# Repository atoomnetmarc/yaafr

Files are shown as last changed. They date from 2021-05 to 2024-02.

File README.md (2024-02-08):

# What are this?

This is Yaafr, Yet Another AVR Fusebit Rescuer. It is large because of all the ZIF-sockets and does not even feature any mounting holes. It also has two IDC headers for expanding to programming clips or other adapters to rescue non-dip AVR microcontrollers.

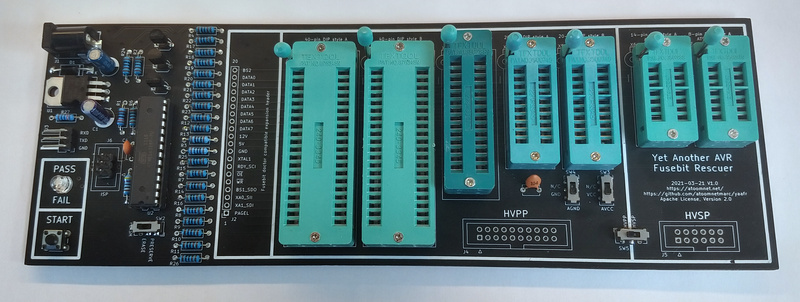
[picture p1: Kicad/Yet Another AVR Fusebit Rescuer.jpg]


It is be able to restore wrongly fused or locked AVR microcontrollers that support high voltage parallel (HVPP) programming or high voltage serial programming (HVSP).

This circuit has been inspired by these projects:

[RescueAVR](https://github.com/felias-fogg/RescueAVR) by Bernhard.\
[AVR Fuse Rescue Shield for Arduino Uno](https://github.com/4x1md/avr_frs_shield) by Dmitry Melnichansky.\
[Arduino-based AVR High Voltage Programmer](https://mightyohm.com/blog/2008/09/arduino-based-avr-high-voltage-programmer/) by Jeff Keyzer.\
[Atmega Fusebit Doctor](https://web.archive.org/web/20180225102717/http://mdiy.pl/atmega-fusebit-doctor-hvpp/?lang=en) by Paweł Kisielewski.

Firmware update 2.11 from the Atmega Fusebit Doctor for the atmega328p has been tested and is working. The [original site](https://files.elektroda.pl/437268,atmega-hvpp-fusebit-doctor_update11.html) does not exist anymore, but [SukkoPera](https://github.com/SukkoPera) has been so kind to archive the remains: https://github.com/SukkoPera/avr-fusebit-doctor/

Firmware from RescueAVR in FBD_MODE works also, but may not contain support for all the chips (such as the AT90S1200).

# Status

This project is working for me, I can rescue all my locked AVRs. See below for what I have tested and validated to be working.

While the schematic was carefully made, the PCB has not been fully tested yet.

I added the possibility to switch on and off AGND and AVCC because in many datasheets in one instance they must be connected and in the next they must not, however leaving the switches always on connected when it does not need to be then the rescues seem to work just fine.

# Checklists

## Functionality

| Thing | Tested and working? |
| -- | -- |
| 40-pin DIP style A | :ballot_box_with_check: |
| 40-pin DIP style B | :ballot_box_with_check: |
| 28-pin DIP style A | :ballot_box_with_check: |
| 20-pin DIP style A | :ballot_box_with_check: |
| 20-pin DIP style B | :ballot_box_with_check: |
| 14-pin DIP style A | :ballot_box_with_check: |
| 8-pin DIP style A | :ballot_box_with_check: |
| AVR Atmega fusebit doctor firmware 2.11 | :ballot_box_with_check: |
| RescueAVR firmware | :ballot_box_with_check: |
| Serial connection | :ballot_box_with_check: |
| Fusebit doctor compatible expansion header | :ballot_box_with_check: |
| HVPP expansion header | :black_square_button: |
| HVSP expansion header | :black_square_button: |

## 40-pin DIP style A (AT90S8535)

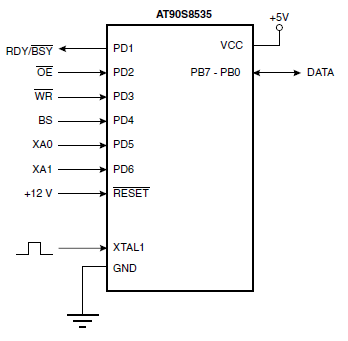
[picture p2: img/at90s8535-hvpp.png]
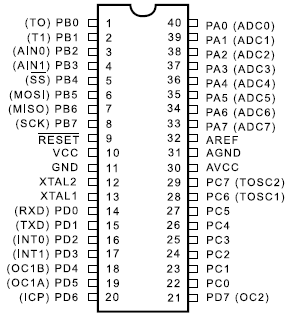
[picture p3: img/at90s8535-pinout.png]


| Model | Signature | Working |
| -- | -- | -- |
| AT90S8535 | 0x1E 0x93 0x03 | :ballot_box_with_check: |
| ATmega8535 | 0x1E 0x93 0x08 | :ballot_box_with_check: |
| ATmega163 | 0x1E 0x94 0x02 | :ballot_box_with_check: |
| ATmega323 | 0x1E 0x95 0x01 | :ballot_box_with_check: |
| ATmega16A | 0x1E 0x94 0x03 | :ballot_box_with_check: |
| ATmega32A | 0x1E 0x95 0x02 | :ballot_box_with_check: |
| ATmega324A | 0x1E 0x95 0x15 | :ballot_box_with_check: |
| ATmega644PA | 0x1E 0x96 0x0A | :ballot_box_with_check: |
| ATmega1284P | 0x1E 0x97 0x05 | :ballot_box_with_check: |

## 40-pin DIP style B (AT90S8515)

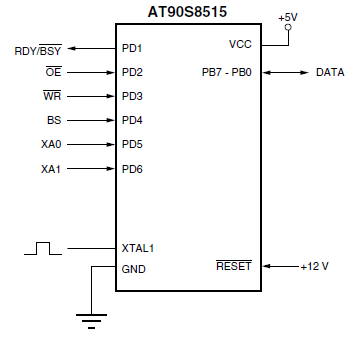
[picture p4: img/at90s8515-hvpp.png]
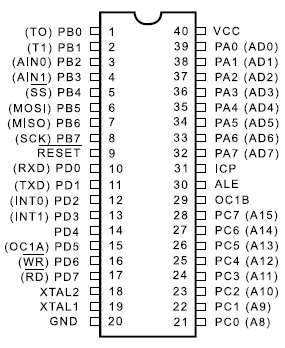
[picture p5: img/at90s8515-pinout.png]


| Model | Signature | Working |
| -- | -- | -- |
| AT90S4414 | 0x1E 0x92 0x01 | :ballot_box_with_check: |
| AT90S8515 | 0x1E 0x93 0x01 | :ballot_box_with_check: |
| ATmega8515 | 0x1E 0x93 0x06 | :ballot_box_with_check: |
| ATmega161 | 0x1E 0x94 0x01 | :ballot_box_with_check: |
| ATmega162 | 0x1E 0x94 0x04 | :ballot_box_with_check: |

## 28-pin DIP style A (AT90S2333)

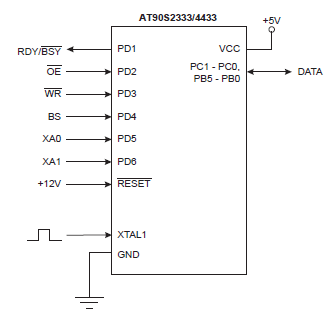
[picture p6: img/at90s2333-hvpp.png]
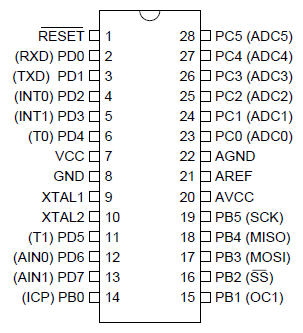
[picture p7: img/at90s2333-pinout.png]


| Model | Signature | Working |
| -- | -- | -- |
| AT90S2333 | 0x1E 0x91 0x05 | :ballot_box_with_check: |
| AT90S4433 | 0x1E 0x92 0x03 | :ballot_box_with_check: |
| ATmega8 | 0x1E 0x93 0x07 | :ballot_box_with_check: |
| ATmega48  | 0x1E 0x92 0x05 | :ballot_box_with_check: |
| ATmega88  | 0x1E 0x93 0x0A | :ballot_box_with_check: |
| ATmega168 | 0x1E 0x94 0x06 | :ballot_box_with_check: |
| ATmega328 | 0x1E 0x95 0x14 | :ballot_box_with_check: |
| ATtiny48  | 0x1E 0x92 0x09 | :ballot_box_with_check: |
| ATtiny88  | 0x1E 0x93 0x11 | :ballot_box_with_check: |

Adapter for TQFP32: https://github.com/atoomnetmarc/Fusebit-Doctor-TQFP32-adapter

## 20-pin DIP style A (AT90S1200)

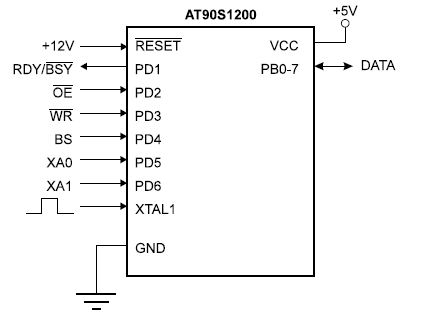
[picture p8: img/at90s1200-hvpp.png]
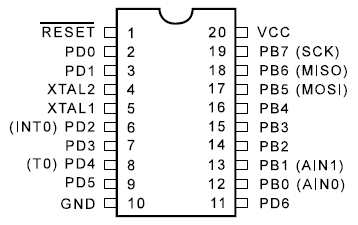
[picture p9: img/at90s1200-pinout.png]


| Model | Signature | Working |
| -- | -- | -- |
| AT90S1200 | 0x1E 0x90 0x01 | :ballot_box_with_check: |
| AT90S2313 | 0x1E 0x91 0x01 | :ballot_box_with_check: |
| ATtiny2313 | 0x1E 0x91 0x0A | :ballot_box_with_check: |
| ATtiny2313A | 0x1E 0x91 0x0A | :ballot_box_with_check: |
| ATtiny4313 | 0x1E 0x92 0x0D | :ballot_box_with_check: |

## 20-pin DIP style B (ATtiny26)

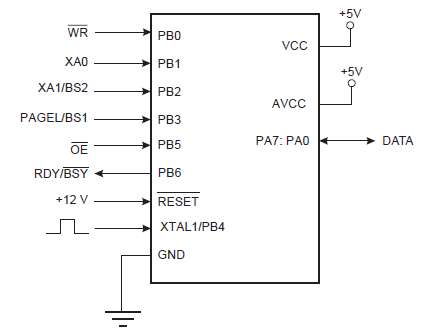
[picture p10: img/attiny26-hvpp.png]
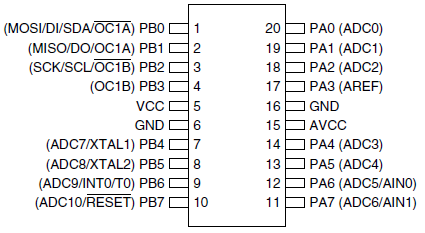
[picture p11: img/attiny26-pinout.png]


| Model | Signature | Working |
| -- | -- | -- |
| ATtiny26 | 0x1E 0x91 0x09 | :ballot_box_with_check: |
| ATtiny261A | 0x1E 0x91 0x0C | :ballot_box_with_check: |
| ATtiny461 | 0x1E 0x92 0x08 | :ballot_box_with_check: |
| ATtiny461A | 0x1E 0x92 0x08 | :ballot_box_with_check: |
| ATtiny861A | 0x1E 0x93 0x0D | :ballot_box_with_check: |

## 14-pin DIP style A (ATtiny24)

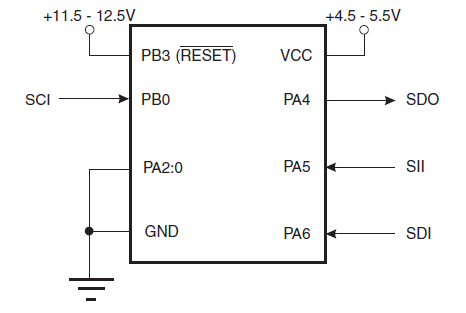
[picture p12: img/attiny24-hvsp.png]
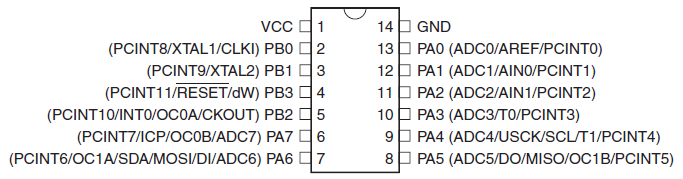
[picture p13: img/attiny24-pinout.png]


| Model | Signature | Working |
| -- | -- | -- |
| ATtiny24  | 0x1E 0x91 0x0B | :ballot_box_with_check: |

## 8-pin DIP style A (AT90S2323)

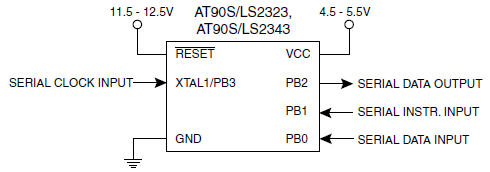
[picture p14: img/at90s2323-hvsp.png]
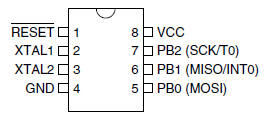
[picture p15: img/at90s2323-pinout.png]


| Model | Signature | Working |
| -- | -- | -- |
| AT90S2323 | 0x1E 0x91 0x02 | :ballot_box_with_check: |
| AT90S2343 | 0x1E 0x91 0x03 | :ballot_box_with_check: |
| ATtiny12  | 0x1E 0x90 0x05 | :ballot_box_with_check: |
| ATtiny15  | 0x1E 0x90 0x06 | :ballot_box_with_check: |
| ATtiny13  | 0x1E 0x90 0x07 | :ballot_box_with_check: |
| ATtiny25  | 0x1E 0x91 0x08 | :ballot_box_with_check: |
| ATtiny45  | 0x1E 0x92 0x06 | :ballot_box_with_check: |
| ATtiny85  | 0x1E 0x93 0x0B | :ballot_box_with_check: |

# Errata

## PCB V1.1

- No known erratum, however this pcb version has not been made yet.

## PCB V1.0

- 10.16mm wide 28-pin ZIF socket X3 seems to be unobtanium. Changed for 7.62mm wide 'narrow' 28-pin zif socket in V1.1 pcb.



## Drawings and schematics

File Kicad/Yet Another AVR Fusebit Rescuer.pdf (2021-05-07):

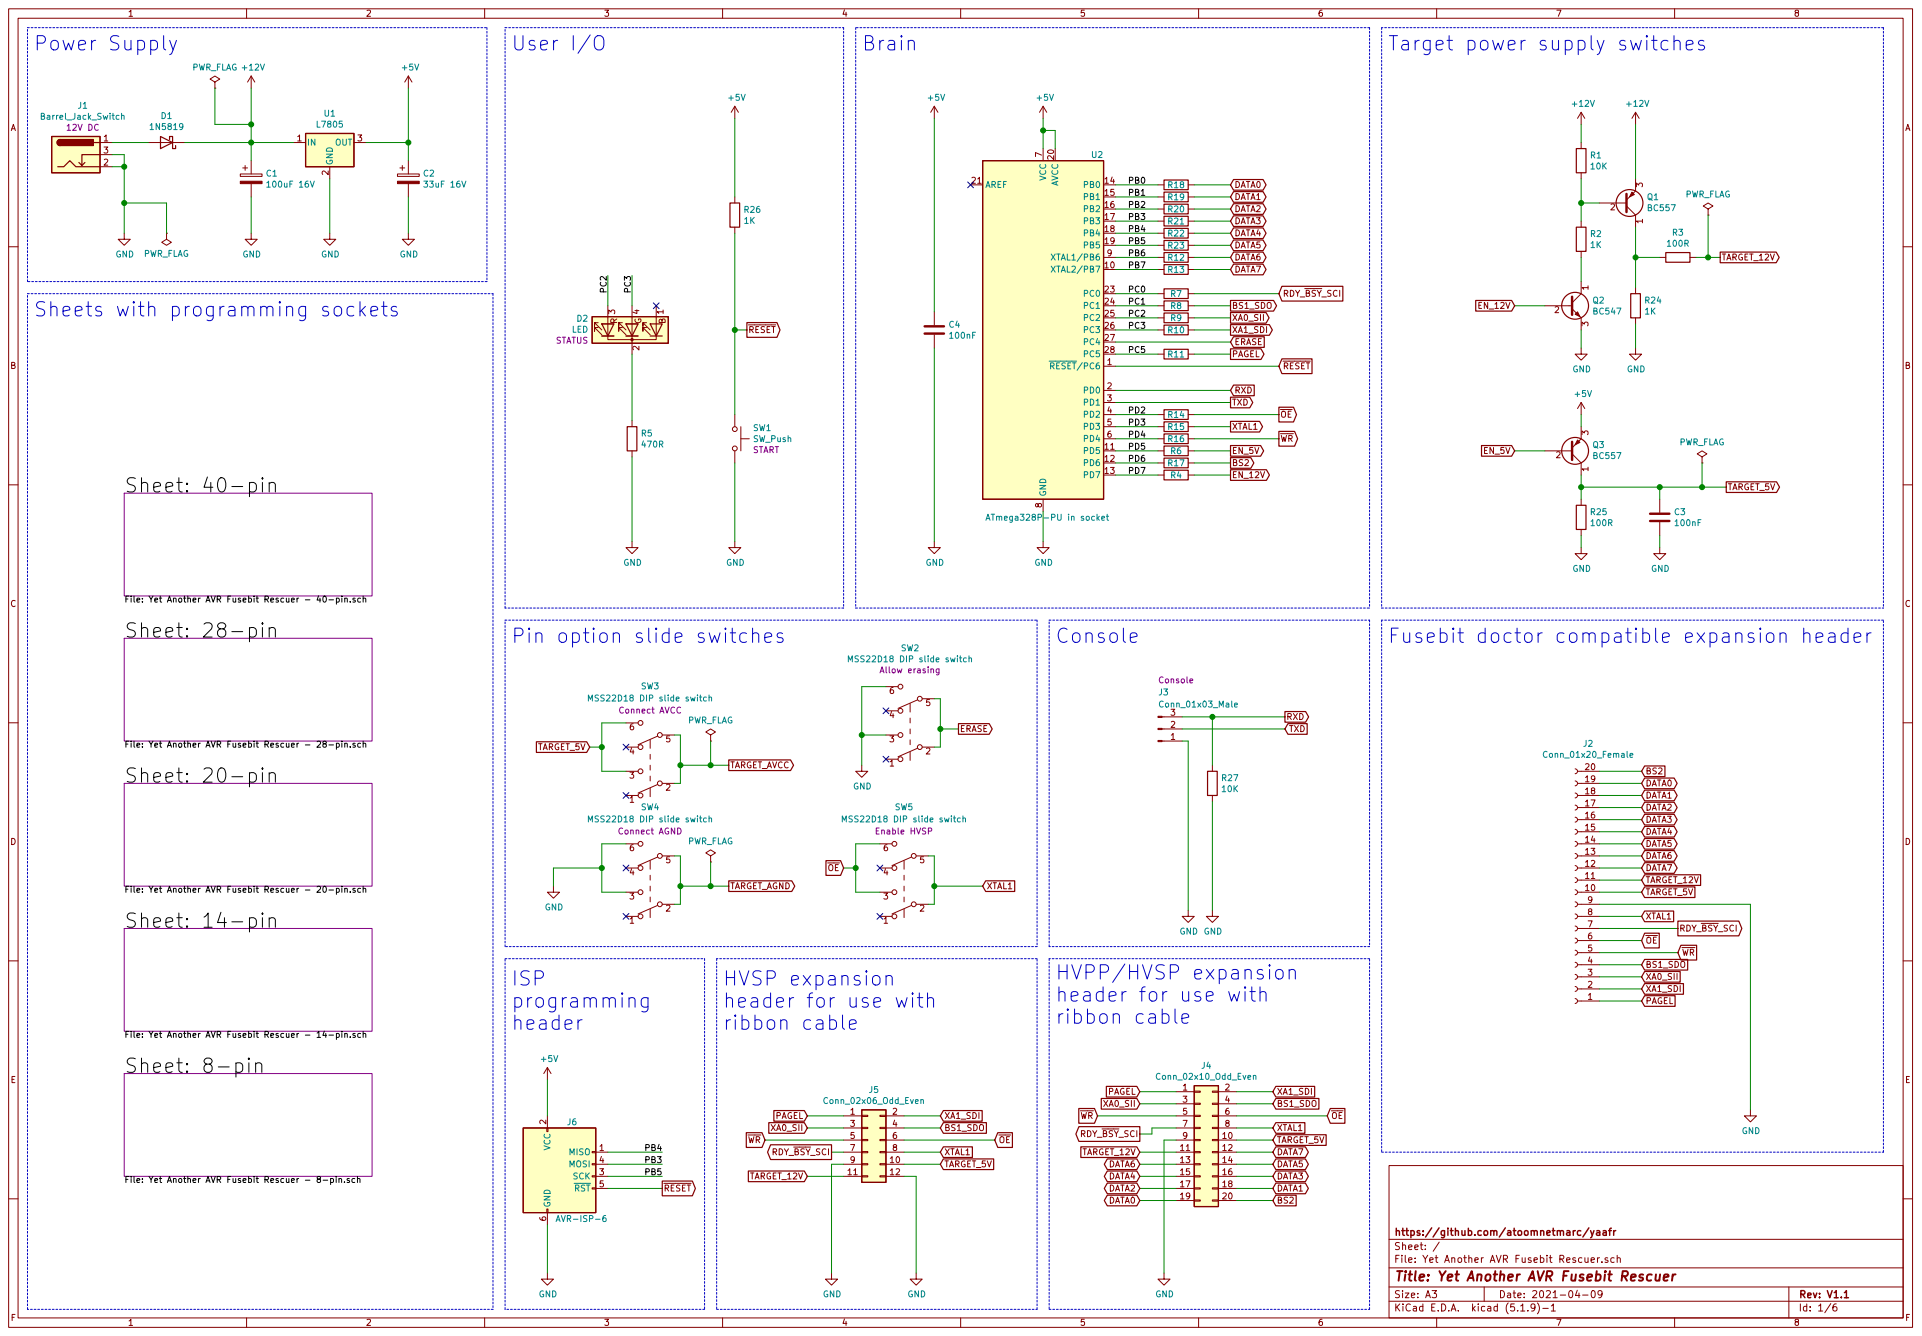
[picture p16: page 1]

Target power supply switches

Sheets with programming sockets

File: Yet Another AVR Fusebit Rescuer - 40-pin.sch
Sheet: 28-pin

6 SW2 MSS22D18 DIP slide switch Allow erasing GND

6 SW3 MSS22D18 DIP slide switch Connect AVCC

File: Yet Another AVR Fusebit Rescuer - 28-pin.sch
Sheet: 20-pin

6 SW4 MSS22D18 DIP slide switch Connect AGND GND

6 SW5 MSS22D18 DIP slide switch Enable HVSP

File: Yet Another AVR Fusebit Rescuer - 20-pin.sch
Sheet: 14-pin

HVPP/HVSP expansion
header for use with
ribbon cable

2 SCK 3 MOSI 4 RST 5 GND

File: Yet Another AVR Fusebit Rescuer - 8-pin.sch

Id: 1/6 Title: Yet Another AVR Fusebit Rescuer File: Yet Another AVR Fusebit Rescuer.sch Sheet: / https://github.com/atoomnetmarc/yaafr

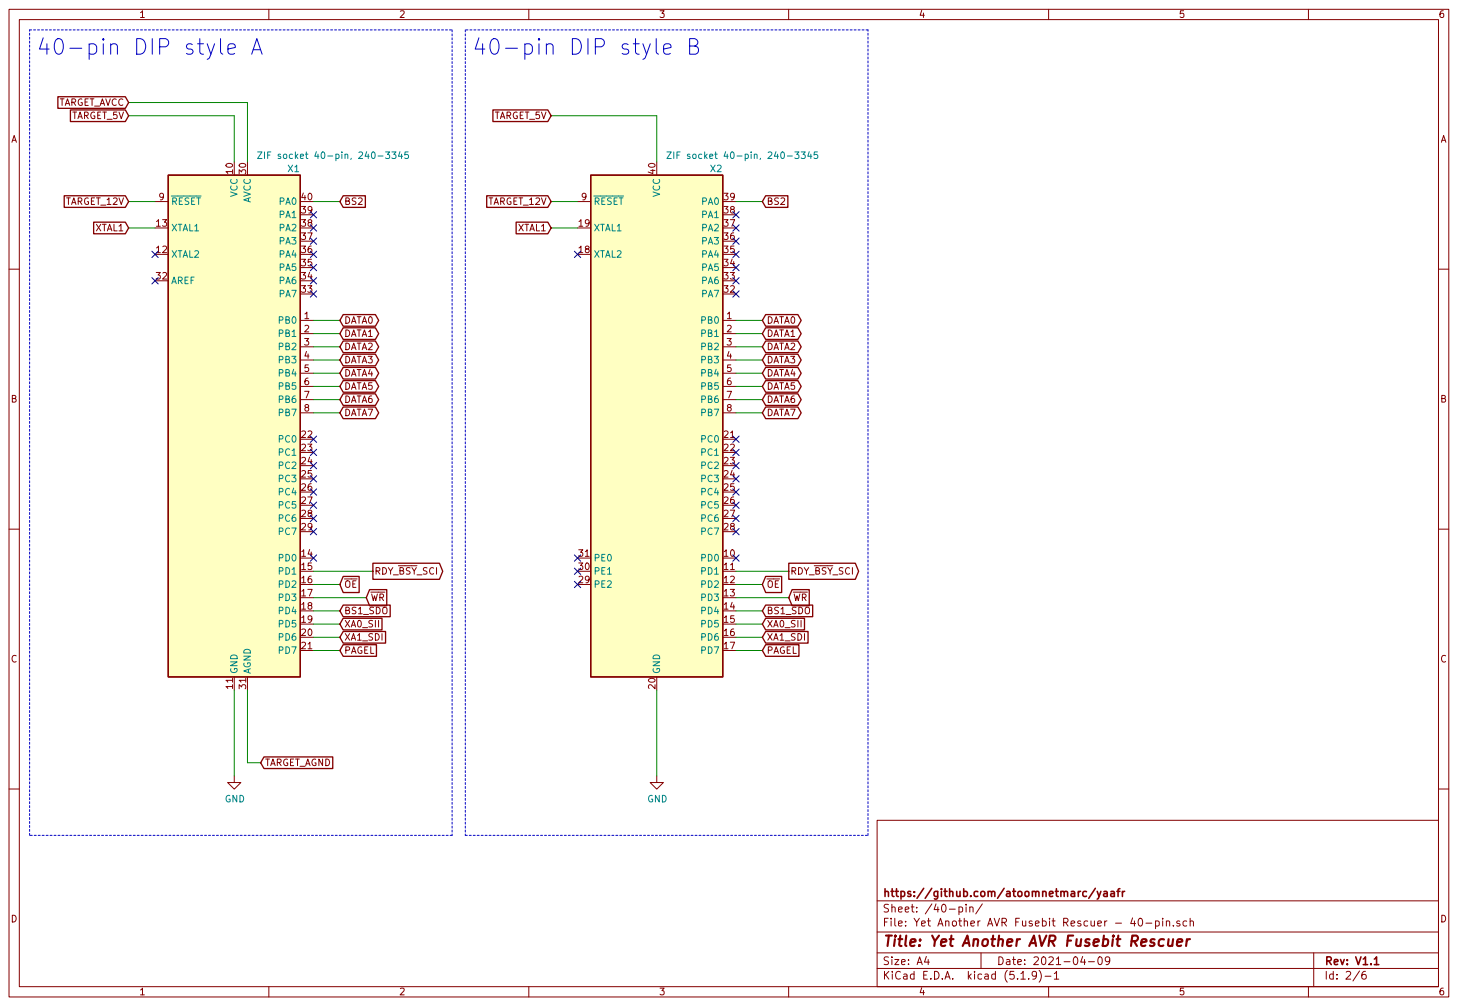
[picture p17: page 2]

https://github.com/atoomnetmarc/yaafr
Sheet: /40-pin/
File: Yet Another AVR Fusebit Rescuer - 40-pin.sch
Id: 2/6 Title: Yet Another AVR Fusebit Rescuer

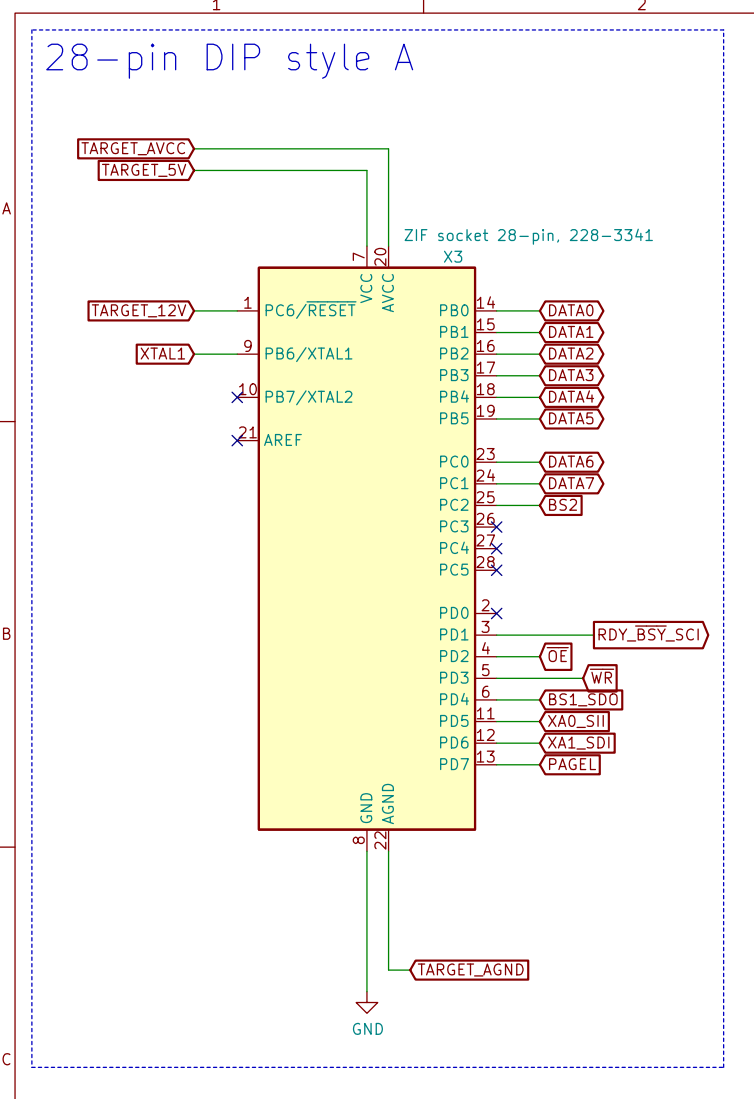
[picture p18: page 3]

8 PB6/XTAL1 9 X3 ZIF socket 28-pin, 228-3341 GND

https://github.com/atoomnetmarc/yaafr
Sheet: /28-pin/
File: Yet Another AVR Fusebit Rescuer - 28-pin.sch
Id: 3/6 Title: Yet Another AVR Fusebit Rescuer

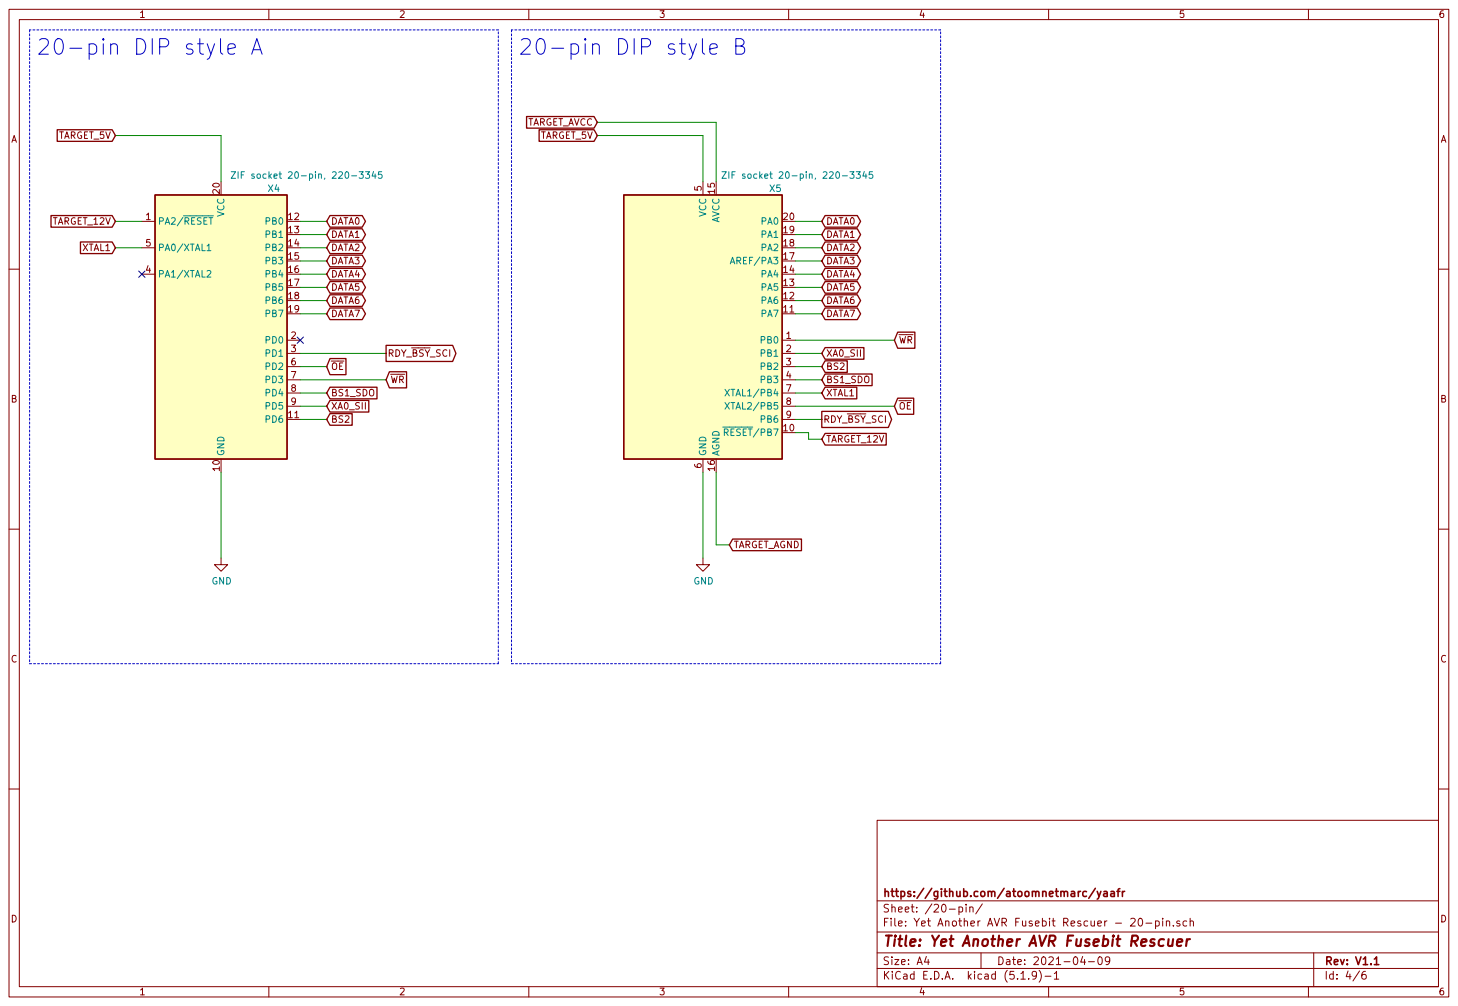
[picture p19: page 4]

6 XTAL1/PB4 7 XTAL2/PB5 8 PB6 9 X5 ZIF socket 20-pin, 220-3345 GND GND WR

https://github.com/atoomnetmarc/yaafr
Sheet: /20-pin/
File: Yet Another AVR Fusebit Rescuer - 20-pin.sch
Id: 4/6 Title: Yet Another AVR Fusebit Rescuer

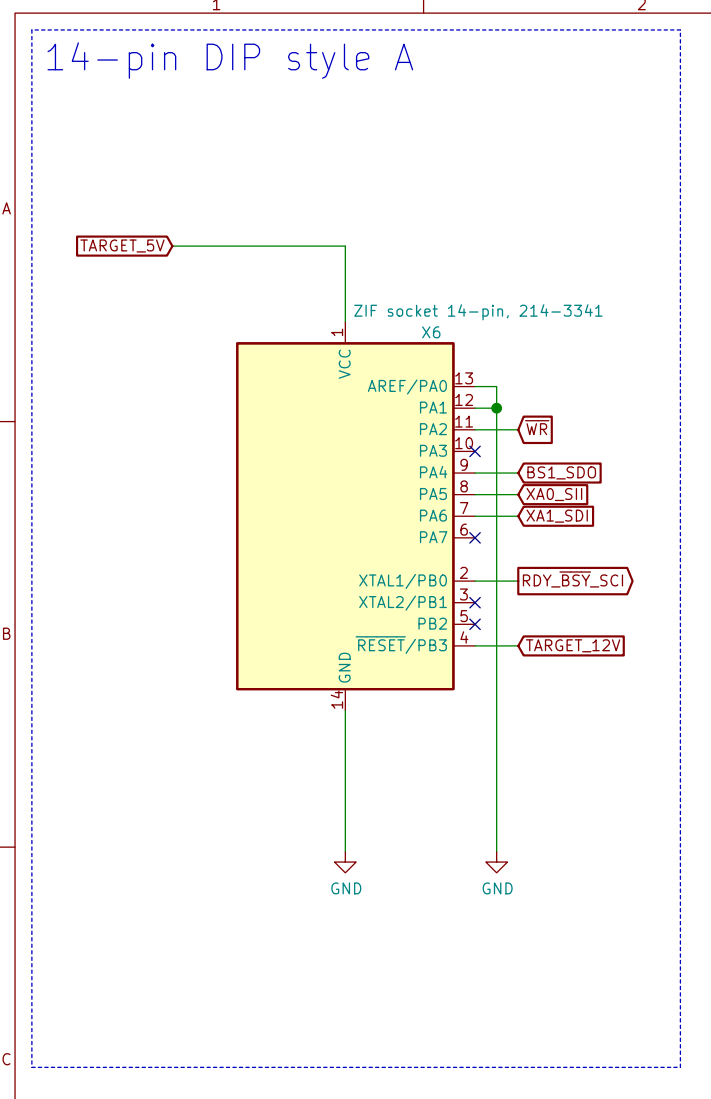
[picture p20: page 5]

1 PA3 10 PA2 11 PA1 12 AREF/PA0 13 GND 14 XTAL1/PB0 2 XTAL2/PB1 3 RESET/PB3 4 PB2 5 PA7 6 PA6 7 PA5 8 PA4 9 X6 ZIF socket 14-pin, 214-3341 BS1_SDO

Sheet: /14-pin/
File: Yet Another AVR Fusebit Rescuer - 14-pin.sch
Id: 5/6 Title: Yet Another AVR Fusebit Rescuer

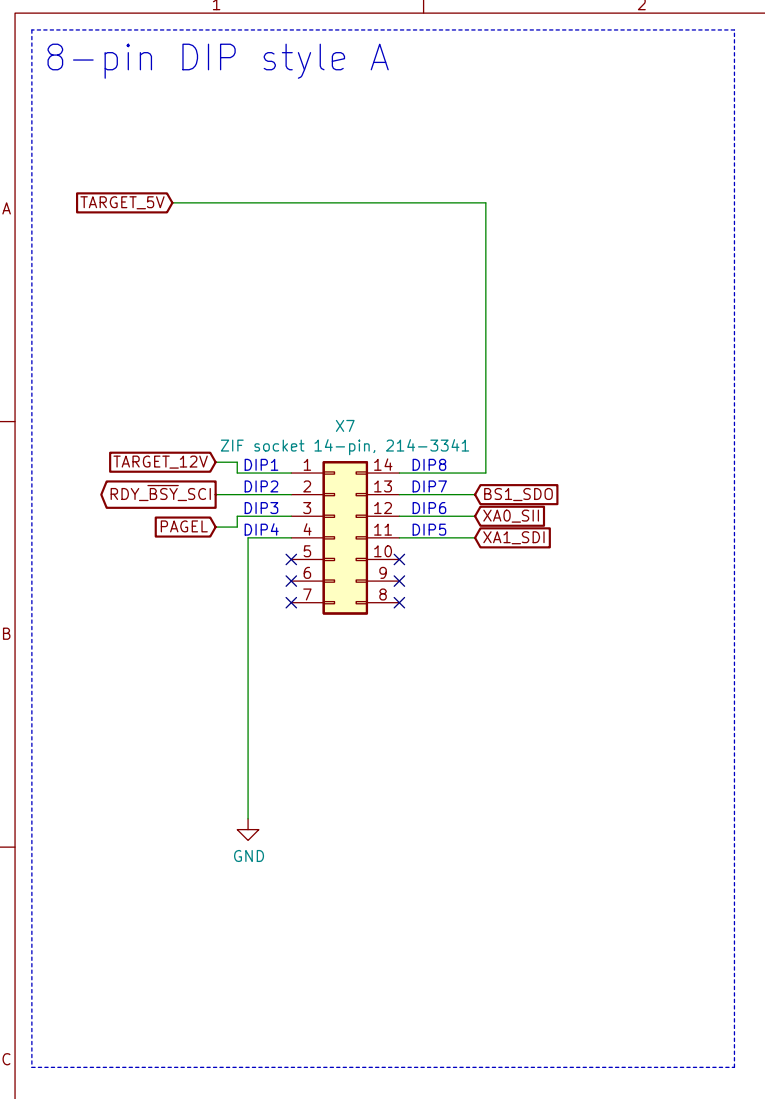
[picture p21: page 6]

https://github.com/atoomnetmarc/yaafr GND

Sheet: /8-pin/
File: Yet Another AVR Fusebit Rescuer - 8-pin.sch
Id: 6/6 Title: Yet Another AVR Fusebit Rescuer

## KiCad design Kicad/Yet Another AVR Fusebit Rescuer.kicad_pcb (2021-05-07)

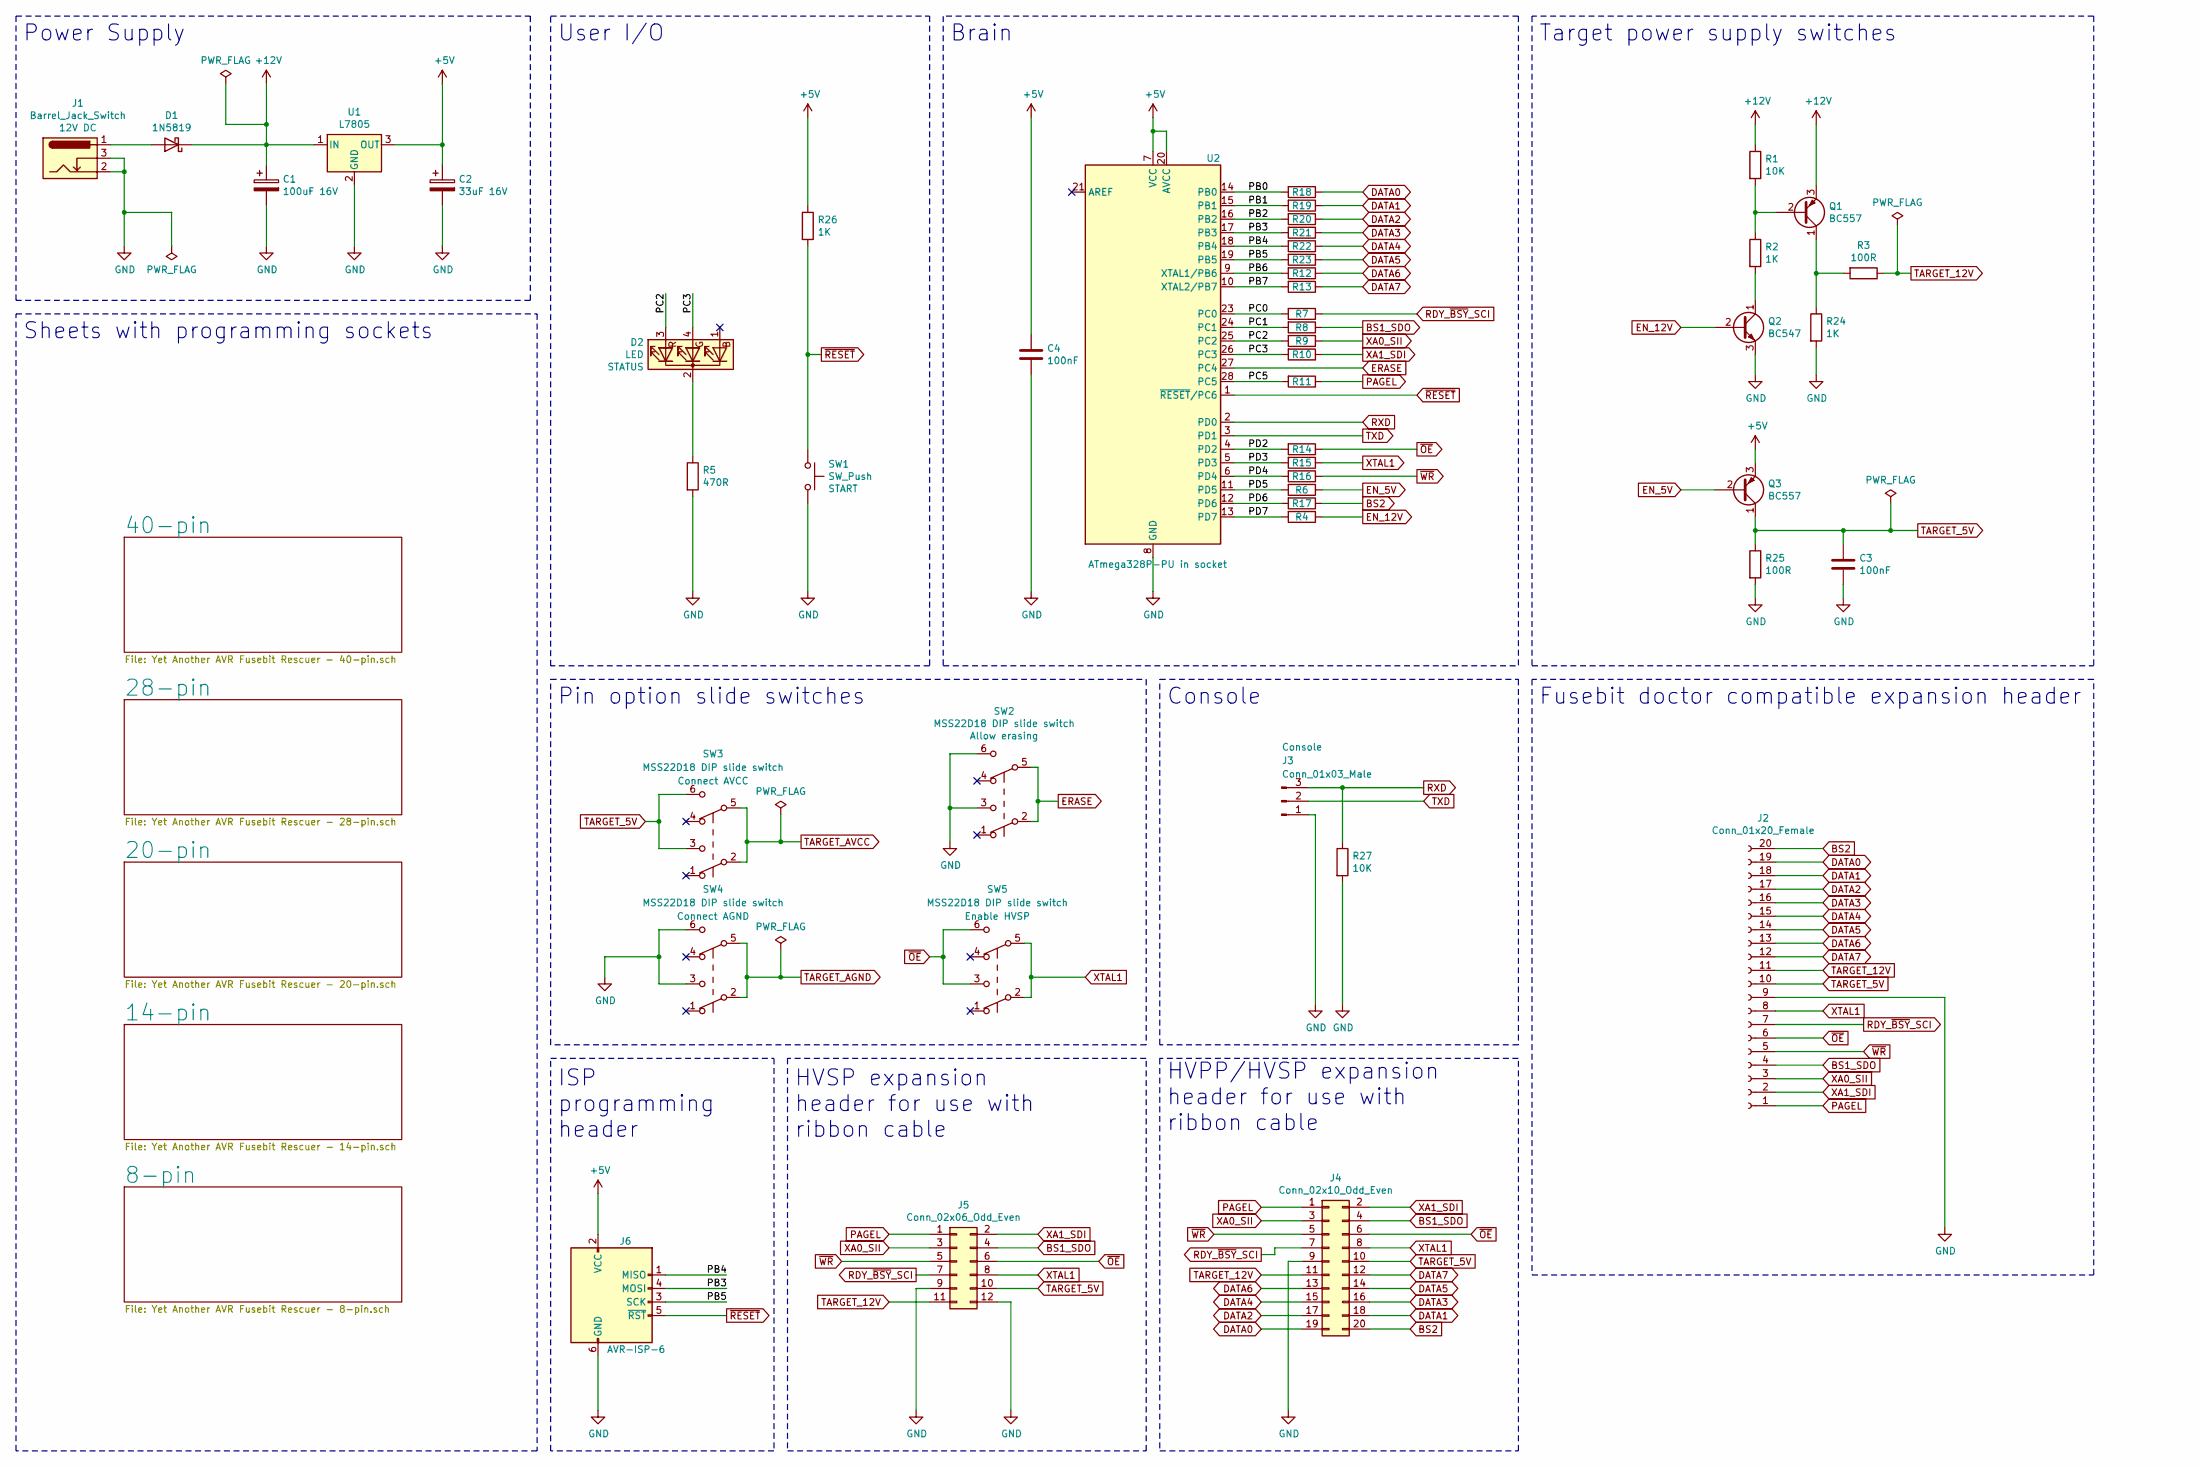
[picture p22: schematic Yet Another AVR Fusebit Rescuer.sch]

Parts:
C1: 100uF 16V; CP_Radial_D6.3mm_P2.50mm
C2: 33uF 16V; CP_Radial_D6.3mm_P2.50mm
C3, C4: 100nF; C_Disc_D5.1mm_W3.2mm_P5.00mm
D1: 1N5819; D_DO-15_P12.70mm_Horizontal
D2: LED; LED_D5.0mm-4_RGB
J1: Barrel_Jack_Switch; BarrelJack_Horizontal
J2: Conn_01x20_Female; PinSocket_1x20_P2.54mm_Vertical
J3: Conn_01x03_Male; PinHeader_1x03_P2.54mm_Horizontal
J4: Conn_02x10_Odd_Even; IDC-Header_2x10_P2.54mm_Vertical
J5: Conn_02x06_Odd_Even; IDC-Header_2x06_P2.54mm_Vertical
J6: AVR-ISP-6; IDC-Header_2x03_P2.54mm_Vertical
Q1, Q3: BC557; TO-92_Wide
Q2: BC547; TO-92_Wide
R1, R27: 10K; R_Axial_DIN0207_L6.3mm_D2.5mm_P10.16mm_Horizontal
R2, R4, R6, R7, R8, R9, R10, R11, R12, R13, R14, R15, R16, R17, R18, R19, R20, R21, R22, R23, R24, R26: 1K; R_Axial_DIN0207_L6.3mm_D2.5mm_P10.16mm_Horizontal
R3, R25: 100R; R_Axial_DIN0207_L6.3mm_D2.5mm_P10.16mm_Horizontal
R5: 470R; R_Axial_DIN0207_L6.3mm_D2.5mm_P10.16mm_Horizontal
SW1: SW_Push; SW_PUSH_6mm
SW2, SW3, SW4, SW5: MSS22D18 DIP slide switch; SW_CuK_JS202011CQN_DPDT_Straight
U1: L7805; TO-220-3_Horizontal_TabDown
U2: ATmega328P-PU in socket; DIP-28_W7.62mm

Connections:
+5V: C2.1, C4.1, J6.2 (VCC), Q3.3 (E), R26.1, U1.3 (OUT), U2.7 (VCC), U2.20 (AVCC)
+12V: C1.1, D1.1 (K), Q1.3 (E), R1.1, U1.1 (IN)
/PB0: R18.2, U2.14 (PB0)
/PB1: R19.2, U2.15 (PB1)
/PB2: R20.2, U2.16 (PB2)
/PB3: J6.4 (MOSI), R21.2, U2.17 (PB3)
/PB4: J6.1 (MISO), R22.2, U2.18 (PB4)
/PB5: J6.3 (SCK), R23.2, U2.19 (PB5)
/PB6: R12.2, U2.9 (XTAL1/PB6)
/PB7: R13.2, U2.10 (XTAL2/PB7)
/PC0: R7.2, U2.23 (PC0)
/PC1: R8.2, U2.24 (PC1)
/PC2: D2.3 (RA), R9.2, U2.25 (PC2)
/PC3: D2.4 (GA), R10.2, U2.26 (PC3)
/PC5: R11.2, U2.28 (PC5)
/PD2: R14.2, U2.4 (PD2)
/PD3: R15.2, U2.5 (PD3)
/PD4: R16.2, U2.6 (PD4)
/PD5: R6.2, U2.11 (PD5)
/PD6: R17.2, U2.12 (PD6)
/PD7: R4.2, U2.13 (PD7)
BS1_SDO: J2.4, J4.4, J5.4, R8.1; also elsewhere on the board
BS2: J2.20, J4.20, R17.1; also elsewhere on the board
DATA0: J2.19, J4.19, R18.1; also elsewhere on the board
DATA1: J2.18, J4.18, R19.1; also elsewhere on the board
DATA2: J2.17, J4.17, R20.1; also elsewhere on the board
DATA3: J2.16, J4.16, R21.1; also elsewhere on the board
DATA4: J2.15, J4.15, R22.1; also elsewhere on the board
DATA5: J2.14, J4.14, R23.1; also elsewhere on the board
DATA6: J2.13, J4.13, R12.1; also elsewhere on the board
DATA7: J2.12, J4.12, R13.1; also elsewhere on the board
EN_5V: Q3.2 (B), R6.1
EN_12V: Q2.2 (B), R4.1
ERASE: SW2.2 (B), SW2.5 (B), U2.27 (PC4)
GND: C1.2, C2.2, C3.2, C4.2, J1.2, J1.3, J2.9, J3.1, J4.9, J5.9, J5.12, J6.6 (GND), Q2.3 (E), R5.2, R24.2, R25.2, R27.2, SW1.2, SW2.3 (C), SW2.6 (C), SW4.3 (C), SW4.6 (C), U1.2 (GND), U2.8 (GND), U2.22 (GND); also elsewhere on the board
unnamed: D1.2 (A), J1.1
unnamed: D2.2 (K), R5.1
unnamed: Q1.1 (C), R3.2, R24.1
unnamed: Q1.2 (B), R1.2, R2.1
unnamed: Q2.1 (C), R2.2
PAGEL: J2.1, J4.1, J5.1, R11.1; also elsewhere on the board
RDY_~BSY~_SCI: J2.7, J4.7, J5.7, R7.1; also elsewhere on the board
RXD: J3.3, R27.1, U2.2 (PD0)
TARGET_5V: C3.1, J2.10, J4.10, J5.10, Q3.1 (C), R25.1, SW3.3 (C), SW3.6 (C); also elsewhere on the board
TARGET_12V: J2.11, J4.11, J5.11, R3.1; also elsewhere on the board
TARGET_AGND: SW4.2 (B), SW4.5 (B); also elsewhere on the board
TARGET_AVCC: SW3.2 (B), SW3.5 (B); also elsewhere on the board
TXD: J3.2, U2.3 (PD1)
XA0_SII: J2.3, J4.3, J5.3, R9.1; also elsewhere on the board
XA1_SDI: J2.2, J4.2, J5.2, R10.1; also elsewhere on the board
XTAL1: J2.8, J4.8, J5.8, R15.1, SW5.2 (B), SW5.5 (B); also elsewhere on the board
~OE: J2.6, J4.6, J5.6, R14.1, SW5.3 (C), SW5.6 (C); also elsewhere on the board
~RESET: J6.5 (~RST), R26.2, SW1.1, U2.1 (~RESET~/PC6)
~WR: J2.5, J4.5, J5.5, R16.1; also elsewhere on the board

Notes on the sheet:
Power Supply
Target power supply switches
Fusebit doctor compatible expansion header
User I/O
Console
Brain
Pin option slide switches
HVPP/HVSP expansion header for use with ribbon cable
HVSP expansion header for use with ribbon cable
ISP programming header
Sheets with programming sockets

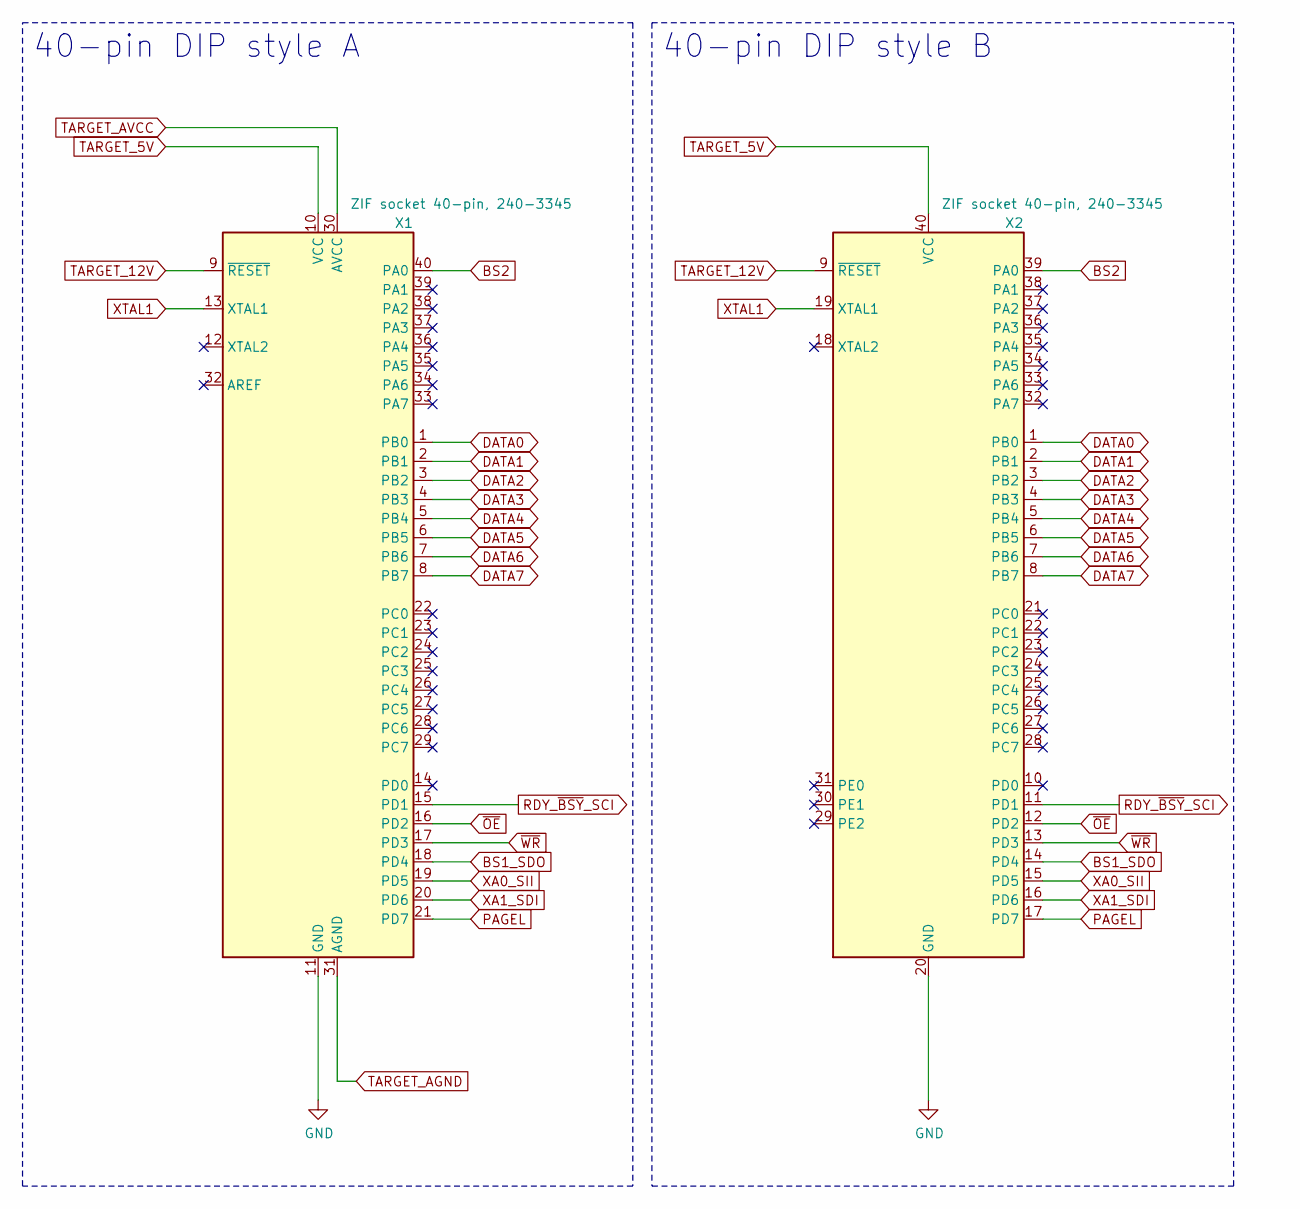
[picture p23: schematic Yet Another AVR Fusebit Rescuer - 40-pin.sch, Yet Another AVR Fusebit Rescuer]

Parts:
X1, X2: ZIF socket 40-pin, 240-3345; DIP_Socket-40_W11.9_W12.7_W15.24_W17.78_W18.5_3M_240-1280-0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

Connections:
BS1_SDO: X1.18 (PD4), X2.14 (PD4); also elsewhere on the board
BS2: X1.40 (PA0), X2.39 (PA0); also elsewhere on the board
DATA0: X1.1 (PB0), X2.1 (PB0); also elsewhere on the board
DATA1: X1.2 (PB1), X2.2 (PB1); also elsewhere on the board
DATA2: X1.3 (PB2), X2.3 (PB2); also elsewhere on the board
DATA3: X1.4 (PB3), X2.4 (PB3); also elsewhere on the board
DATA4: X1.5 (PB4), X2.5 (PB4); also elsewhere on the board
DATA5: X1.6 (PB5), X2.6 (PB5); also elsewhere on the board
DATA6: X1.7 (PB6), X2.7 (PB6); also elsewhere on the board
DATA7: X1.8 (PB7), X2.8 (PB7); also elsewhere on the board
GND: X1.11 (GND), X2.20 (GND); also elsewhere on the board
PAGEL: X1.21 (PD7), X2.17 (PD7); also elsewhere on the board
RDY_~BSY~_SCI: X1.15 (PD1), X2.11 (PD1); also elsewhere on the board
TARGET_5V: X1.10 (VCC), X2.40 (VCC); also elsewhere on the board
TARGET_12V: X1.9 (~RESET), X2.9 (~RESET); also elsewhere on the board
TARGET_AGND: X1.31 (AGND); also elsewhere on the board
TARGET_AVCC: X1.30 (AVCC); also elsewhere on the board
XA0_SII: X1.19 (PD5), X2.15 (PD5); also elsewhere on the board
XA1_SDI: X1.20 (PD6), X2.16 (PD6); also elsewhere on the board
XTAL1: X1.13 (XTAL1), X2.19 (XTAL1); also elsewhere on the board
~OE: X1.16 (PD2), X2.12 (PD2); also elsewhere on the board
~WR: X1.17 (PD3), X2.13 (PD3); also elsewhere on the board

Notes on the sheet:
40-pin DIP style A
40-pin DIP style B

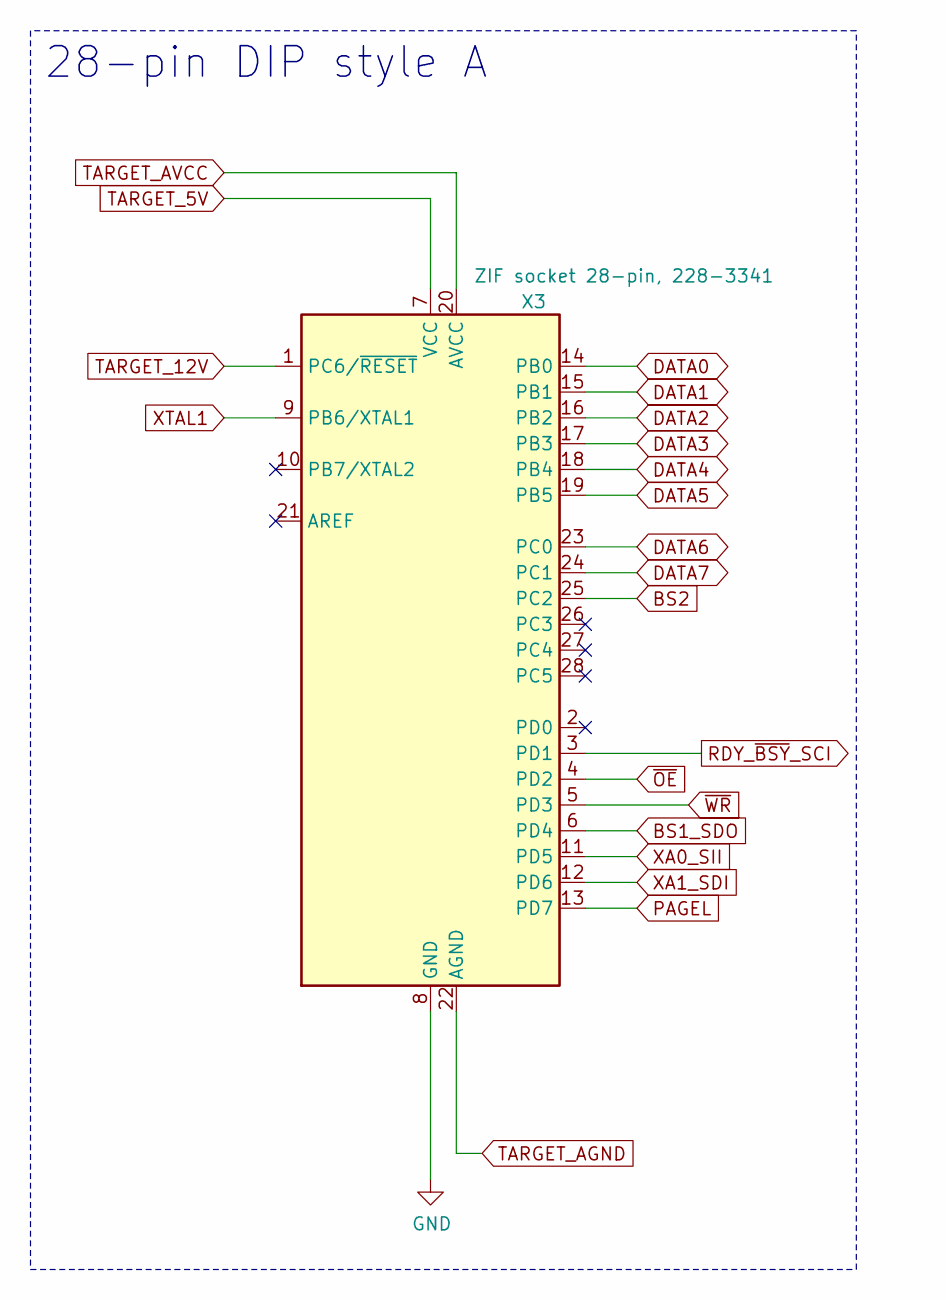
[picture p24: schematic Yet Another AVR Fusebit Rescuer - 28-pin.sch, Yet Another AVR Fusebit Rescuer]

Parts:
X3: ZIF socket 28-pin, 228-3341; DIP_Socket-28_228-3341

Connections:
BS1_SDO: X3.6 (PD4); also elsewhere on the board
BS2: X3.25 (PC2); also elsewhere on the board
DATA0: X3.14 (PB0); also elsewhere on the board
DATA1: X3.15 (PB1); also elsewhere on the board
DATA2: X3.16 (PB2); also elsewhere on the board
DATA3: X3.17 (PB3); also elsewhere on the board
DATA4: X3.18 (PB4); also elsewhere on the board
DATA5: X3.19 (PB5); also elsewhere on the board
DATA6: X3.23 (PC0); also elsewhere on the board
DATA7: X3.24 (PC1); also elsewhere on the board
GND: X3.8 (GND); also elsewhere on the board
PAGEL: X3.13 (PD7); also elsewhere on the board
RDY_~BSY~_SCI: X3.3 (PD1); also elsewhere on the board
TARGET_5V: X3.7 (VCC); also elsewhere on the board
TARGET_12V: X3.1 (PC6/~RESET); also elsewhere on the board
TARGET_AGND: X3.22 (AGND); also elsewhere on the board
TARGET_AVCC: X3.20 (AVCC); also elsewhere on the board
XA0_SII: X3.11 (PD5); also elsewhere on the board
XA1_SDI: X3.12 (PD6); also elsewhere on the board
XTAL1: X3.9 (PB6/XTAL1); also elsewhere on the board
~OE: X3.4 (PD2); also elsewhere on the board
~WR: X3.5 (PD3); also elsewhere on the board

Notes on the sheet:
28-pin DIP style A

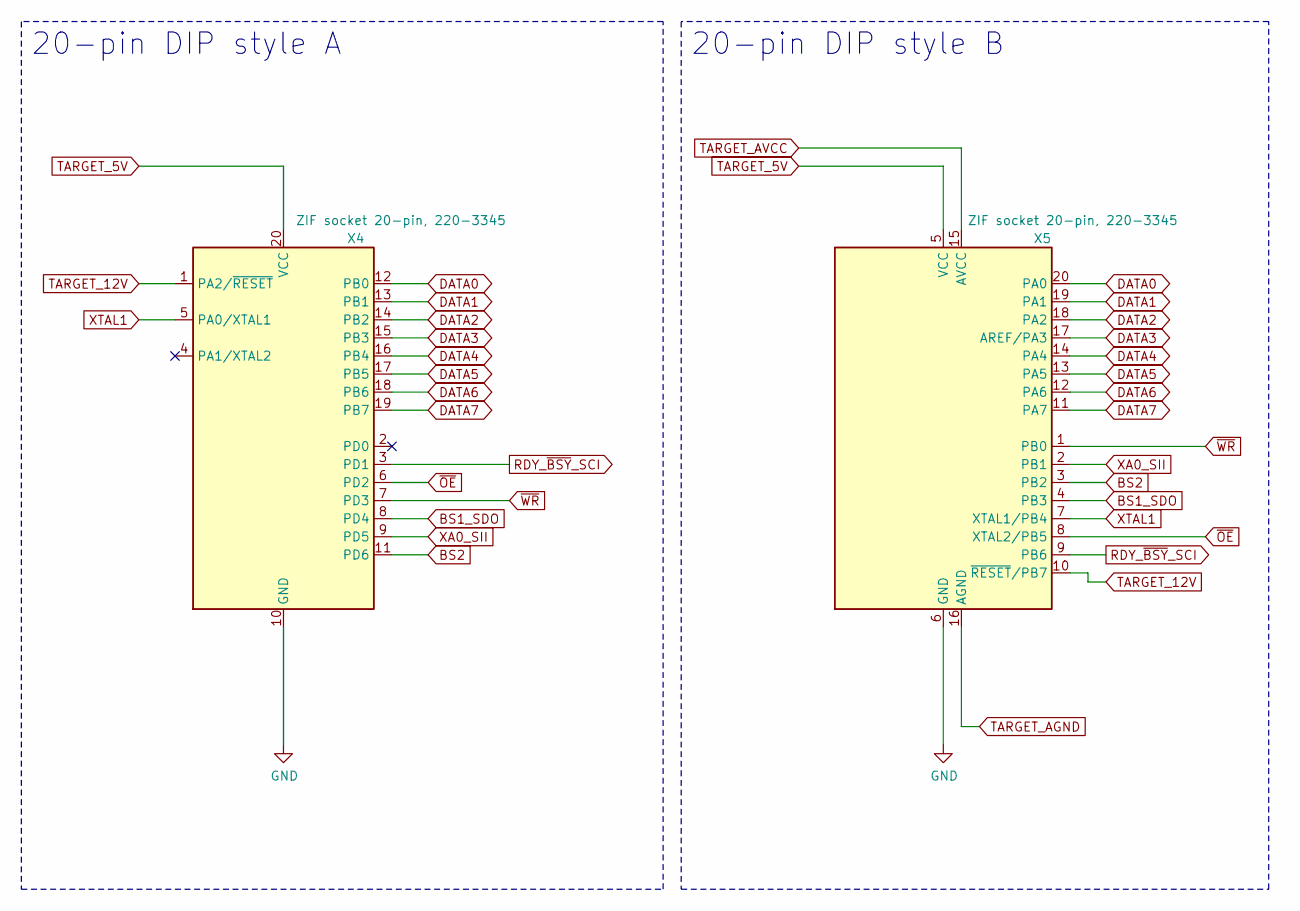
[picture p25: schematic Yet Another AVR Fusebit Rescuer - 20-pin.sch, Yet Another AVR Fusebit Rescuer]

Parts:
X4, X5: ZIF socket 20-pin, 220-3345; DIP_Socket-20_W4.3_W5.08_W7.62_W10.16_W10.9_3M_220-3342-00-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

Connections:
BS1_SDO: X4.8 (PD4), X5.4 (PB3); also elsewhere on the board
BS2: X4.11 (PD6), X5.3 (PB2); also elsewhere on the board
DATA0: X4.12 (PB0), X5.20 (PA0); also elsewhere on the board
DATA1: X4.13 (PB1), X5.19 (PA1); also elsewhere on the board
DATA2: X4.14 (PB2), X5.18 (PA2); also elsewhere on the board
DATA3: X4.15 (PB3), X5.17 (AREF/PA3); also elsewhere on the board
DATA4: X4.16 (PB4), X5.14 (PA4); also elsewhere on the board
DATA5: X4.17 (PB5), X5.13 (PA5); also elsewhere on the board
DATA6: X4.18 (PB6), X5.12 (PA6); also elsewhere on the board
DATA7: X4.19 (PB7), X5.11 (PA7); also elsewhere on the board
GND: X4.10 (GND), X5.6 (GND); also elsewhere on the board
RDY_~BSY~_SCI: X4.3 (PD1), X5.9 (PB6); also elsewhere on the board
TARGET_5V: X4.20 (VCC), X5.5 (VCC); also elsewhere on the board
TARGET_12V: X4.1 (PA2/~RESET), X5.10 (~RESET~/PB7); also elsewhere on the board
TARGET_AGND: X5.16 (AGND); also elsewhere on the board
TARGET_AVCC: X5.15 (AVCC); also elsewhere on the board
XA0_SII: X4.9 (PD5), X5.2 (PB1); also elsewhere on the board
XTAL1: X4.5 (PA0/XTAL1), X5.7 (XTAL1/PB4); also elsewhere on the board
~OE: X4.6 (PD2), X5.8 (XTAL2/PB5); also elsewhere on the board
~WR: X4.7 (PD3), X5.1 (PB0); also elsewhere on the board

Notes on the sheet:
20-pin DIP style A
20-pin DIP style B

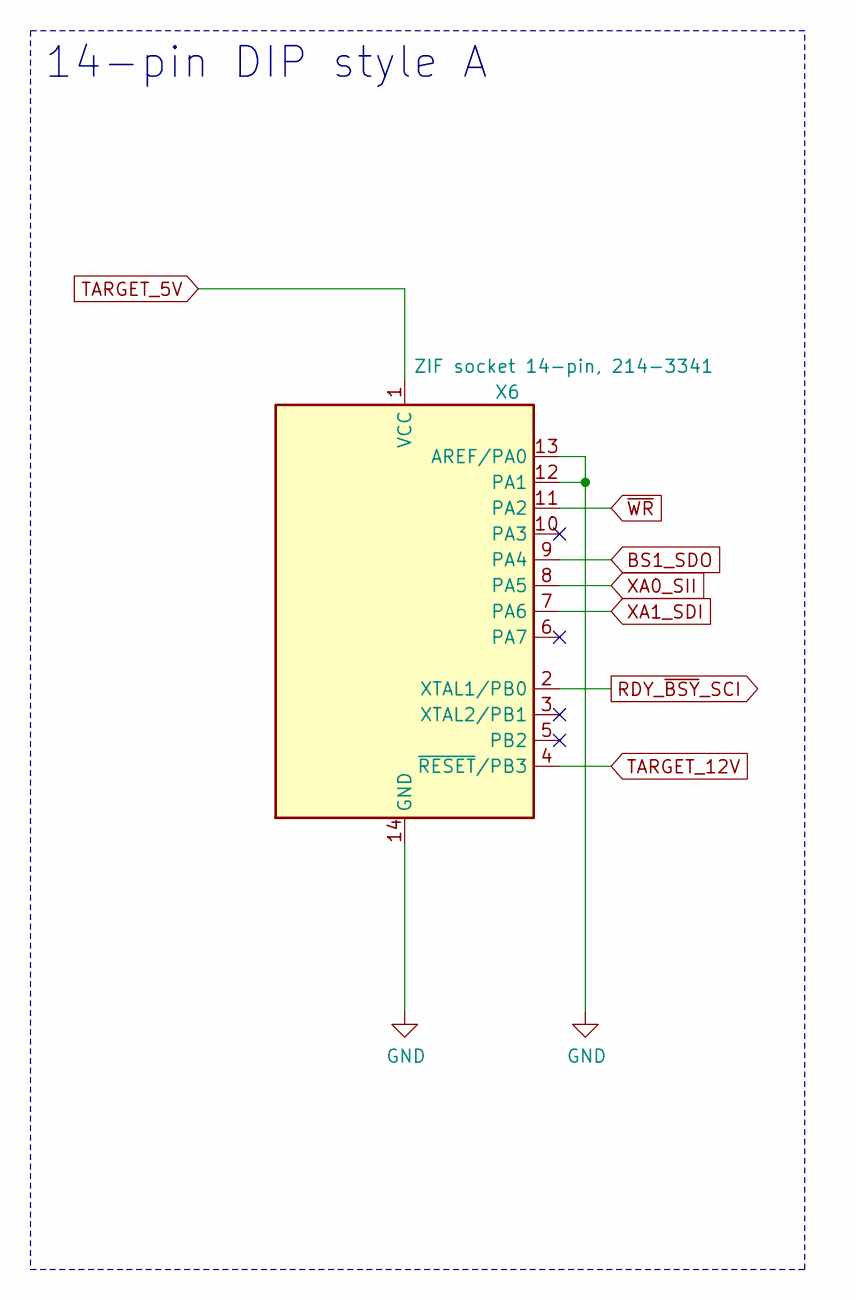
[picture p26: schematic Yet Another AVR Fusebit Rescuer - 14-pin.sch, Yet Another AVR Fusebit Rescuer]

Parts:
X6: ZIF socket 14-pin, 214-3341; DIP_Socket-14_W4.3_W5.08_W7.62_W10.16_W10.9_3M_214-3339-00-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

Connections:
BS1_SDO: X6.9 (PA4); also elsewhere on the board
GND: X6.12 (PA1), X6.13 (AREF/PA0), X6.14 (GND); also elsewhere on the board
RDY_~BSY~_SCI: X6.2 (XTAL1/PB0); also elsewhere on the board
TARGET_5V: X6.1 (VCC); also elsewhere on the board
TARGET_12V: X6.4 (~RESET~/PB3); also elsewhere on the board
XA0_SII: X6.8 (PA5); also elsewhere on the board
XA1_SDI: X6.7 (PA6); also elsewhere on the board
~WR: X6.11 (PA2); also elsewhere on the board

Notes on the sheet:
14-pin DIP style A

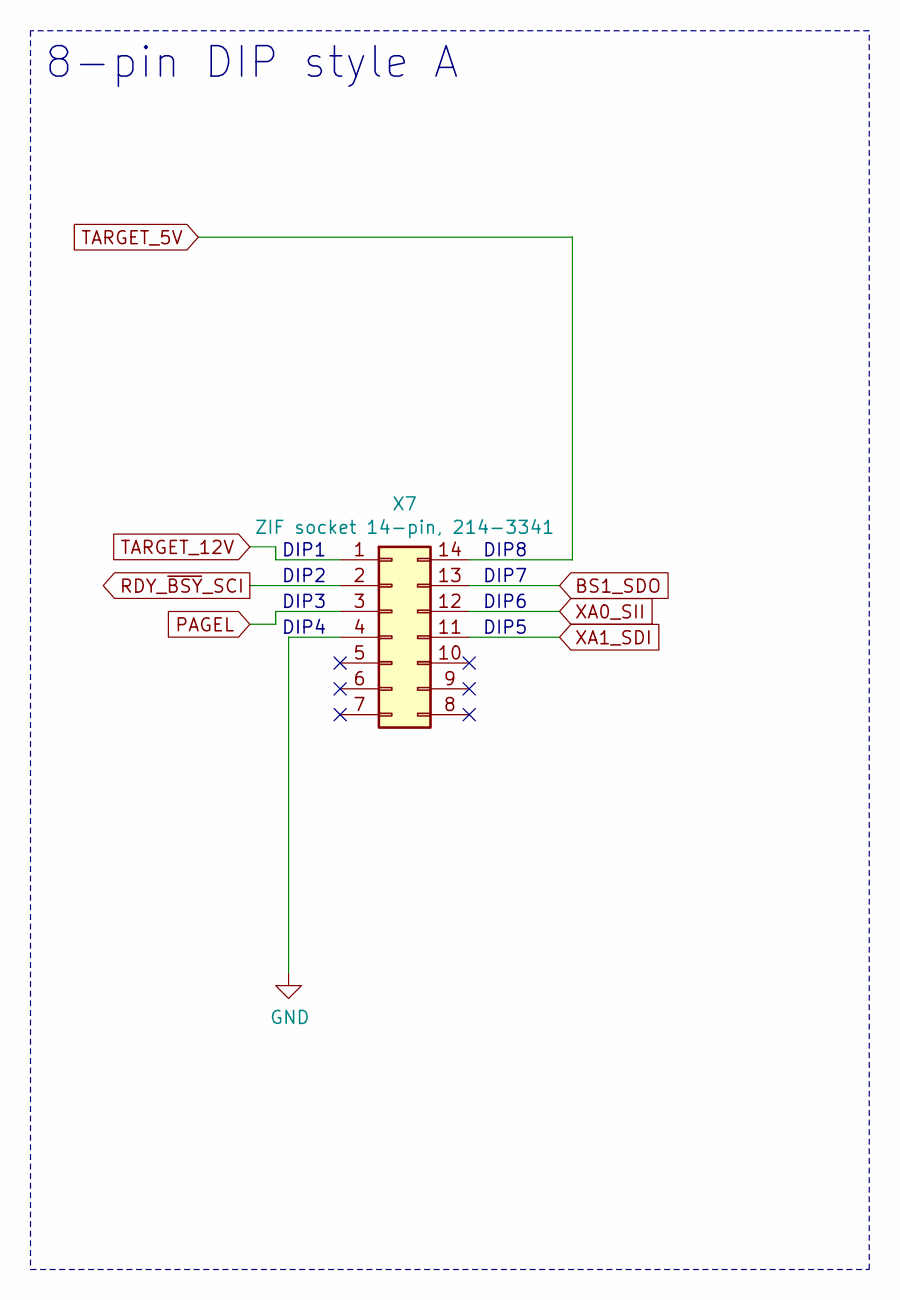
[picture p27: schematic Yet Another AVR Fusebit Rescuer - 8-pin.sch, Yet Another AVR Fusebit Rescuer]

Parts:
X7: ZIF socket 14-pin, 214-3341; DIP_Socket-14_W4.3_W5.08_W7.62_W10.16_W10.9_3M_214-3339-00-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

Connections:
BS1_SDO: X7.13; also elsewhere on the board
GND: X7.4; also elsewhere on the board
PAGEL: X7.3; also elsewhere on the board
RDY_~BSY~_SCI: X7.2; also elsewhere on the board
TARGET_5V: X7.14; also elsewhere on the board
TARGET_12V: X7.1; also elsewhere on the board
XA0_SII: X7.12; also elsewhere on the board
XA1_SDI: X7.11; also elsewhere on the board

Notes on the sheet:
8-pin DIP style A
DIP5
DIP6
DIP7
DIP8
DIP1
DIP2
DIP3
DIP4

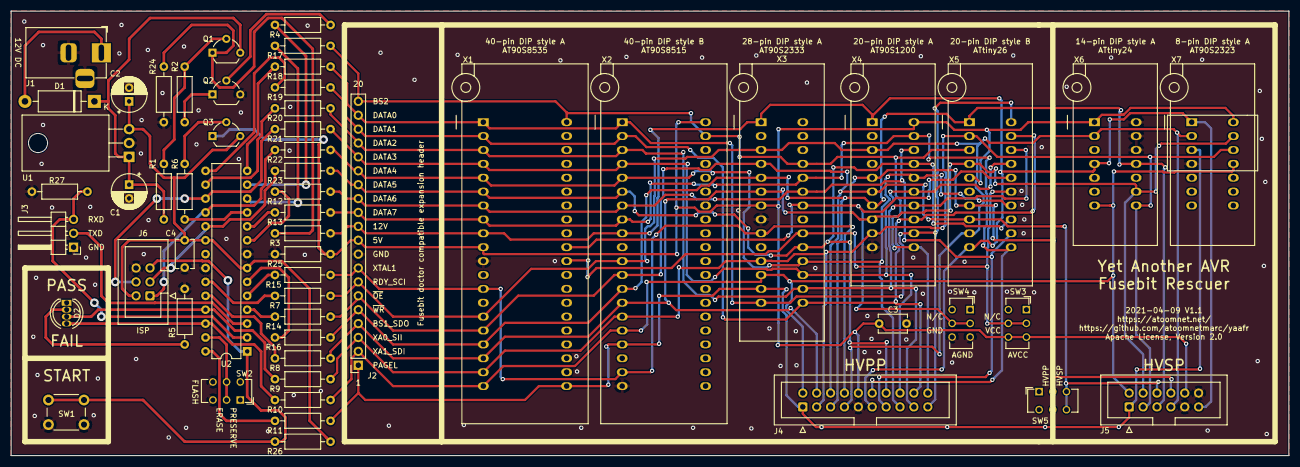
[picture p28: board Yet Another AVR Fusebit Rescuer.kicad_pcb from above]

Board: 2 copper layers, 233.7 x 81.3 mm, 56 parts (0 on the bottom side), 54 nets.

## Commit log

2023-03-06 Updated dead link to Atmega Fusebit Doctor.
2024-02-08 Fusebit doctor compatible expansion header tested and working.

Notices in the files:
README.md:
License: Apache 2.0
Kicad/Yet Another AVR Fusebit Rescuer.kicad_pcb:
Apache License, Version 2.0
